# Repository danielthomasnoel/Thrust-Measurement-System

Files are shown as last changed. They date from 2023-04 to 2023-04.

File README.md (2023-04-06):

The Thrust Measurement System (TMS) was conceived to collect reliable propeller performance data in a pedagogical environment. An iterative design review process brought the thrust measurement system from an idea to a product. It applies mechatronic principles to the exploration and quantification of basic fluid dynamics properties, providing a way for the user to accurately measure the thrust generated by a propeller at a variable angular velocity. The TMD is driven by an Arduino microcontroller that collects data from a load cell and an inferred sensor to calculate the thrust and RPM of an attached propellor. LCD screens display both the thrust and RPMs in real time. The propellor’s angular velocity is determined by a potentiometer that limits the power supplied to a DC motor, allowing the user to adjust the rate at which the propellor is turning. This data is recorded and stored on an onboard SD card for further analysis. To maximize the audience and application of the TMD, its construction is designed to be repeatable exportable to other educators.

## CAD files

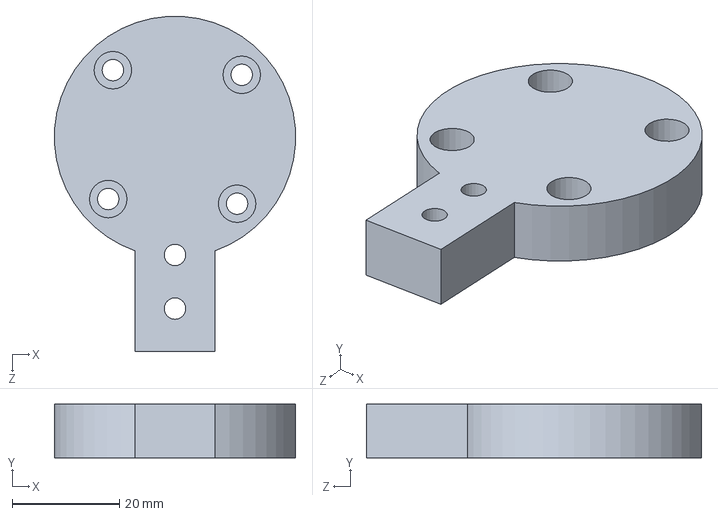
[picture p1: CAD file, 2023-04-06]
DC Motor Mount.SLDPRT
44.9 x 10.0 x 62.5 mm

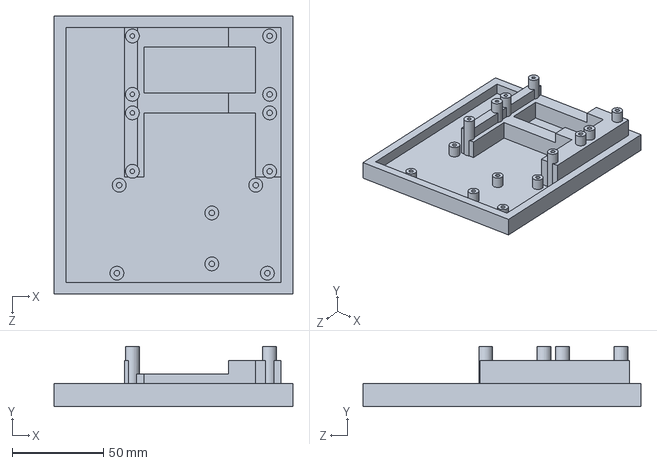
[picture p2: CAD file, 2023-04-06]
Thrust Measurement Control Box.SLDPRT
130.8 x 33.0 x 152.4 mm

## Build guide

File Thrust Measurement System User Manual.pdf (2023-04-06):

Thrust Measurement System User Manual

Daniel Noel¹

, Dr. Michael Davis¹

1University of Southern Maine

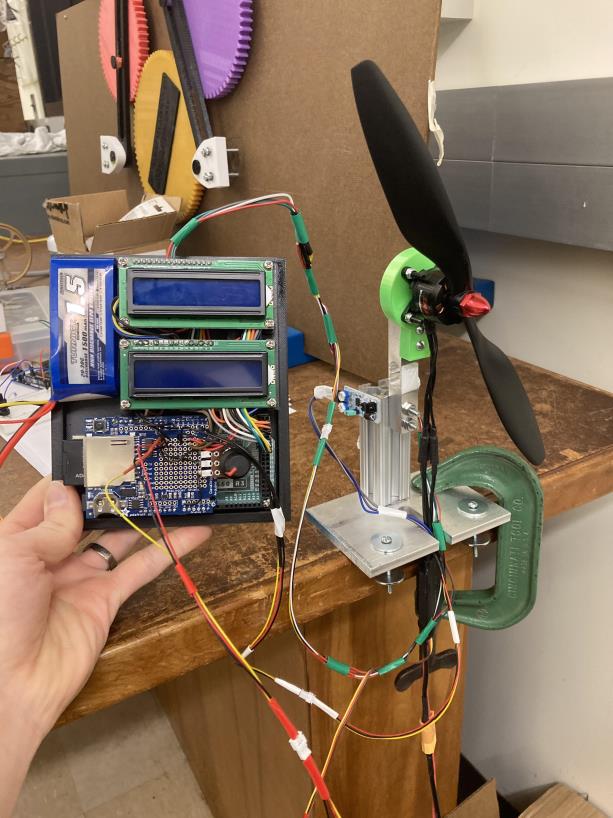
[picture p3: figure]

Author Note

This report was generated as part of the 2022-23 Undergraduate Research Opportunities

Program and was funded by the Maine Space Grant Consortium.

Table of Contents

Purpose

The Thrust Measurement System (TMS) was conceived to collect reliable propeller

performance data in a pedagogical environment. An iterative design review process brought the

thrust measurement device from an idea to a product. It applies mechatronic principles to the

exploration and quantification of basic fluid dynamics properties, providing a way for the user to

accurately measure the thrust generated by a propeller at a variable angular velocity. The TMS is

driven by an Arduino microcontroller that collects data from a load cell and an inferred sensor to

calculate the thrust and RPM of an attached propellor. LCD screens display both the thrust and

RPMs in real time. The propellor’s angular velocity is determined by a potentiometer that limits

the power supplied to a DC motor, allowing the user to adjust the rate at which the propellor is

turning. This data is recorded and stored on an onboard SD card for further analysis. To

maximize the audience and application of the TMS, its construction is designed to be repeatable

exportable to other educators.

Brief Aerodynamics Overview

Thrust is explained by Newton’s third law which states that for every action there is an

equal and opposite reaction. The TMS measures the reaction force generated by the propellor.

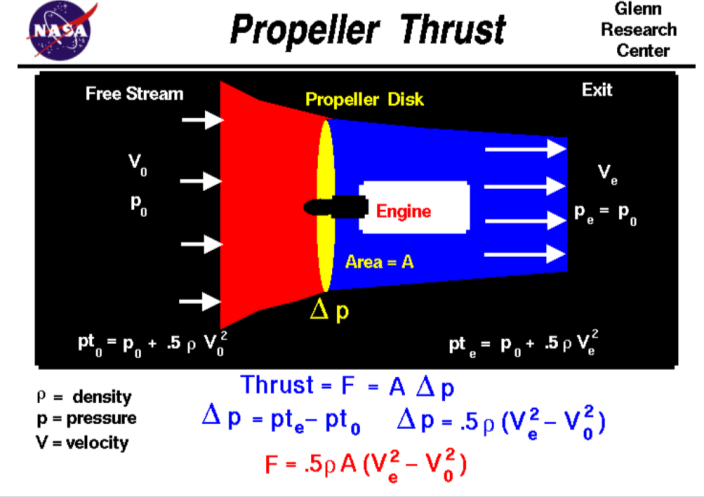
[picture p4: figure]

This is seen in the figure where the thrust

is equal to the product of the propeller’s

area and the pressure difference that it

creates. This pressure differential is the

result of energy conservation and is

proportional to the air’s change in

velocity as it passes through the propeller.

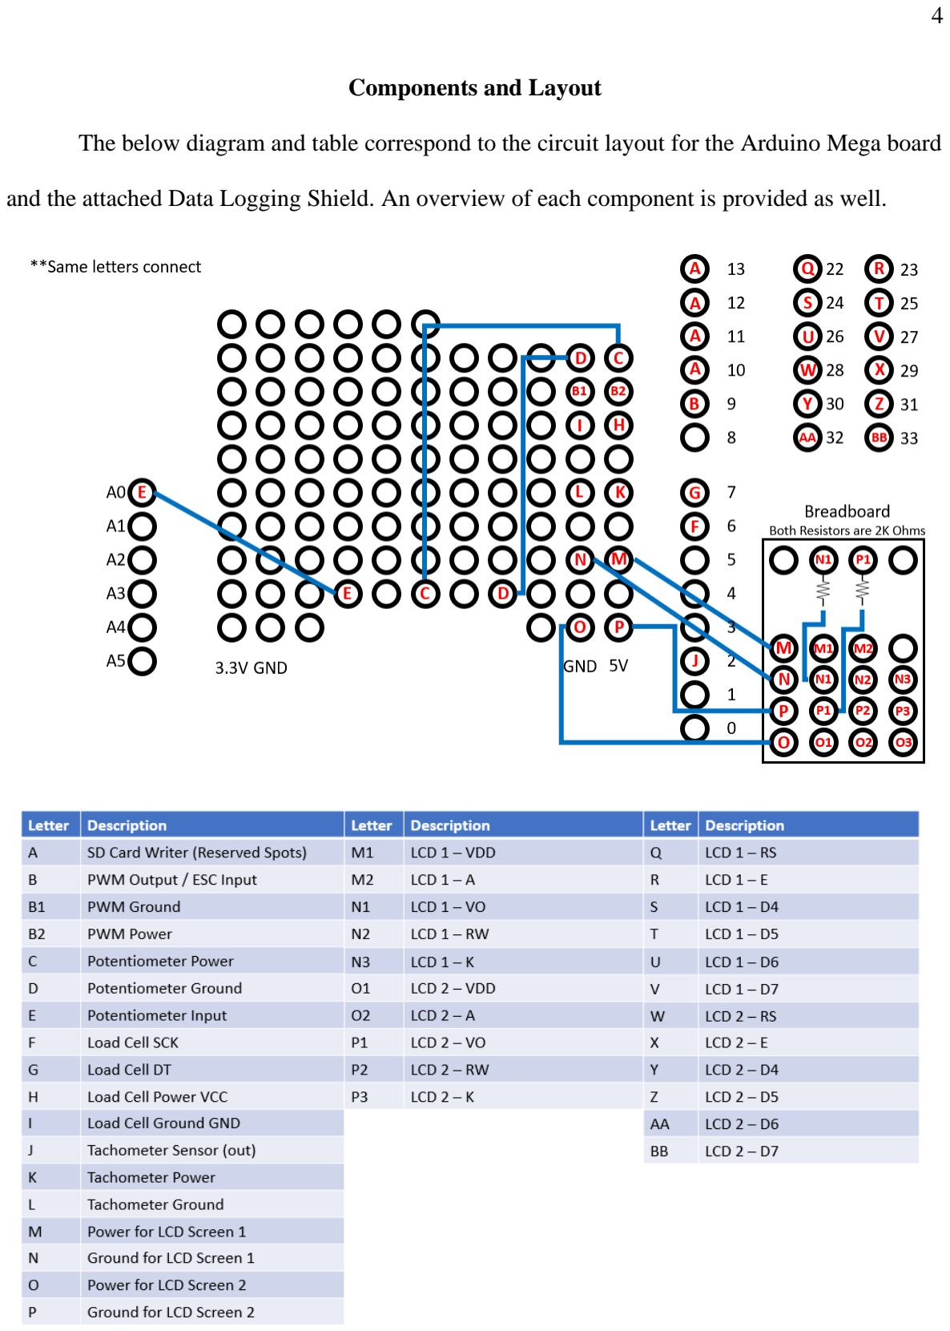
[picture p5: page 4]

Components and Layout

The below diagram and table correspond to the circuit layout for the Arduino Mega board

and the attached Data Logging Shield. An overview of each component is provided as well.

Arduino Mega 2560 R3

The Arduino Mega is a microcontroller board. It has 54 digital

input/output pins, 16 analog inputs, 4 hardware serial ports, a 16

MHz crystal oscillator, a USB connection, a power jack, and a

reset button. All components in the TMS are controlled by and

connected to this device.

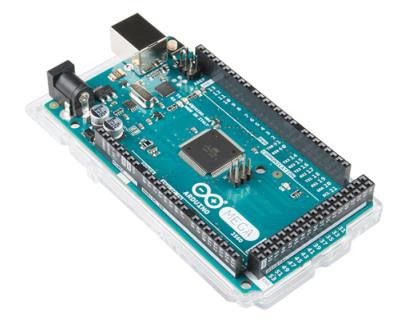
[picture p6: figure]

DC Turbine

The EMAX Multi copter motor MT2213-935KV was used as the DC

turbine. This system allowed for pulse width modulation control which

allows the user to adjust the RPMs of the propellor. This device can rotate

both clockwise and counterclockwise.

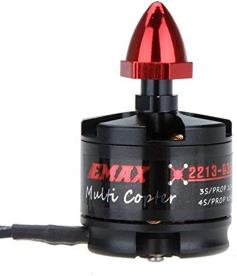
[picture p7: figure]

Potentiometer

The chosen potentiometer was the Panel Mount Right Angle

Potentiometer. It contains a standard linear taper of 10K Ohms,

and it also comes equipped with an on/off switch at the

beginning of the shaft's rotation.

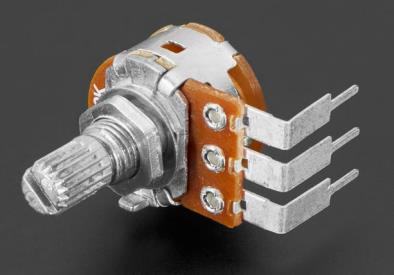
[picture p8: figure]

Load Cell

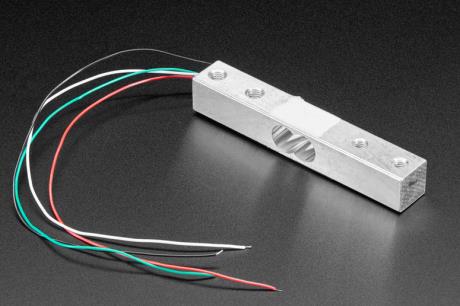
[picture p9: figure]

The load cell chosen was from Adafruit and has a 5kg max

limit. It is a device that converts a force, such as weight,

pressure, or torque, into an electrical signal that can be

measured and standardized.

Tachometer

The Velleman Obstacle Detection IR Sensor was used as a

tachometer by recognizing every time a propellor blade passes

in front of its field of view. It can interface directly with

Arduino, and it also has variable frequency and intensity.

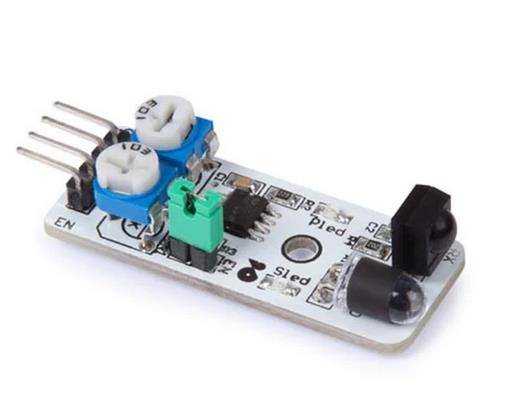
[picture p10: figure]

LCD Screen

The two screens used in the system were HD44780 LCDs.

They display 16 characters wide and 2 rows deep. One was

used to display thrust and the other RPMs.

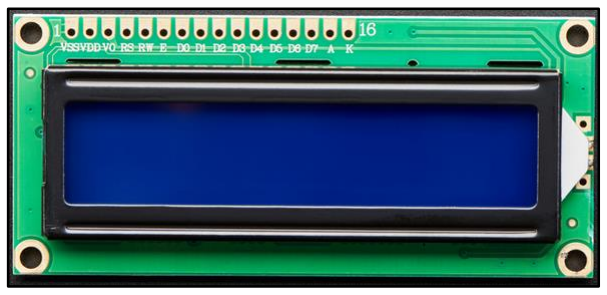
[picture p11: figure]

Data Logging Shield

The data logging shield used was Adafruit Assembled Data

Logging Shield for Arduino. It reads data from the system

outputs and writes them to a removable SD card. This shield

mounts directly on top of the Arduino Mega board.

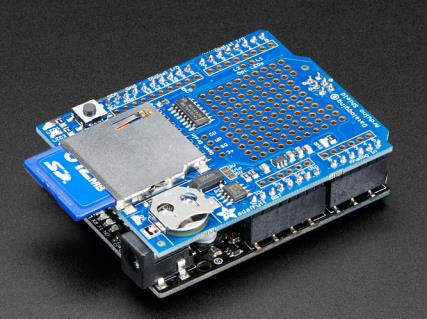
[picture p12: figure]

### 3 Cell 11.1V 1500mAh Battery

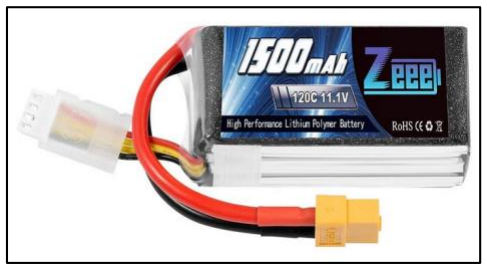
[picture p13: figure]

The type of battery chosen for this project was a 3 Cell

11.1V, 1.5A, 1500mAh battery. A more or less powerful

battery could be substituted if a different range of thrust is

desired.

Arduino Code

The code that needs to be uploaded to the assembled Arduino Mega can be found on

TMS’s GitHub page: https://github.com/danielthomasnoel/Thrust-Measurement-Device. The

code is annotated, but the two main items that may need to be changed for a different setup are

lines 28 and 115. Line 28 is the calibration factor for the load cell which is explained further in

the calibration section. Line 115 needs to be modified depending on how many blades are on the

propellor.

Case Design and Assembly

This system was designed specifically to meet the size requirements of USM’s AeroLab

wind tunnel. The board case will not need to be resized, however for different applications it is

recommended to design all other components to meet specific requirements. The CAD files for

the board case and DC motor mount can be found on the TMS’s GitHub page:

https://github.com/danielthomasnoel/Thrust-Measurement-Device.

The current design requires a soldering station as about 20 connections need to be

soldered directly to the data logging shield. This number can be increased or decreased

depending on the specific specifications of components procured for this build.

Board Case and DC Motor Mount

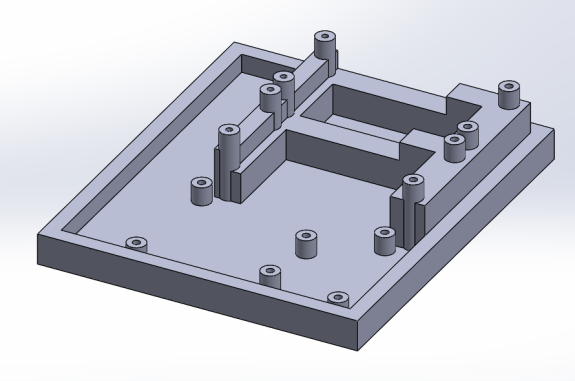
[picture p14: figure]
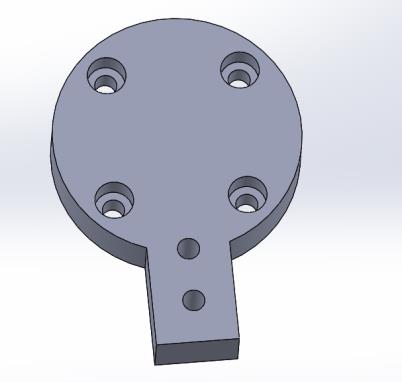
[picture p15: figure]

The board case (left) was designed to fit two LCD screens, 1500 mA battery pack,

Arduino Mega, and data logging shield. All fasteners are sized to have slight interference with

M3 fasteners. The DC motor mount (right) was designed to attach the EMAX DC Turbine to the

load cell. As stated earlier, the specific dimensions of this piece may vary depending on the

system’s size requirements.

Thrust Stand Mount

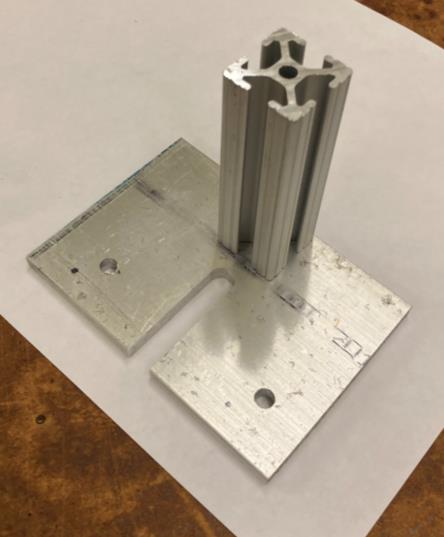
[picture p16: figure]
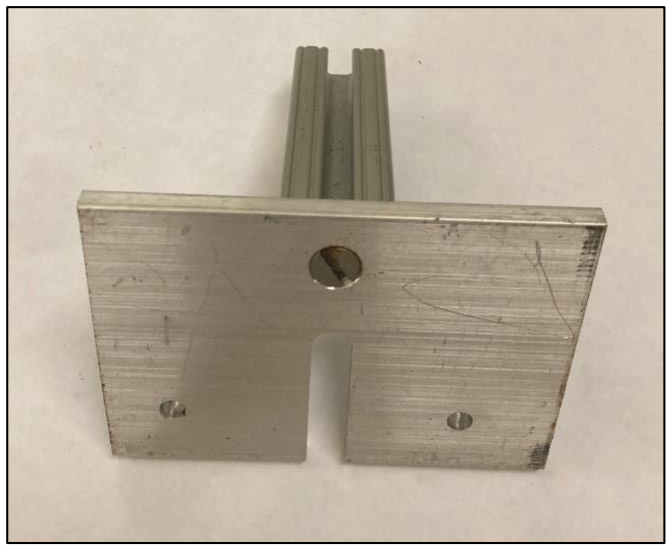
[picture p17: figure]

The aluminum base and 1” 8020 post were sized to fit USM’s AeroLab wind tunnel.

Full Setup

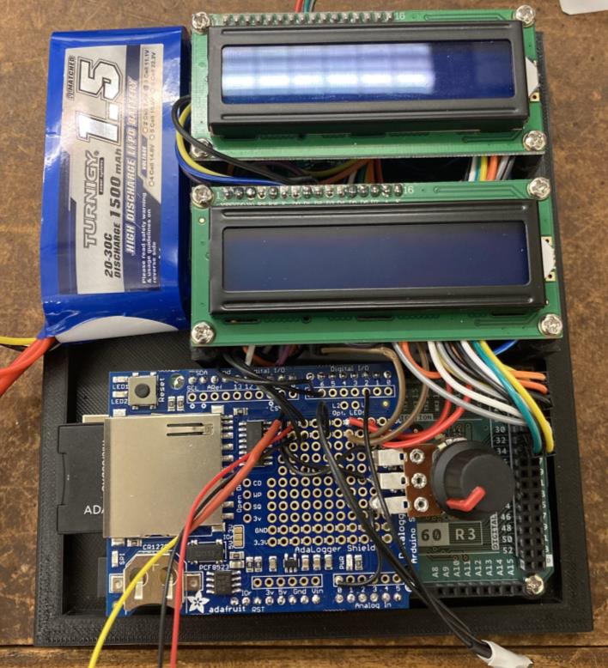
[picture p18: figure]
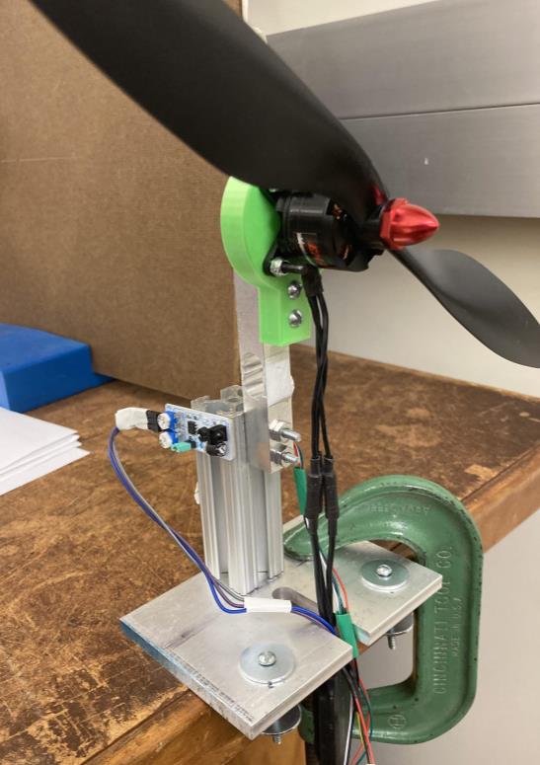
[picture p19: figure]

The fully assembled Thrust Stand Mount (left) is shown with the EMAX DC motor, DC

motor mount, load cell, and tachometer attached. The fully assembled control system is shown

fastened to the Board case. It contains two LCD screens, battery, Arduino Mega, data writing

shield, and potentiometer.

Operation

The first step to operation is to upload the Arduino code from the TMS GitHub to the

fully assembled Arduino Mega and components. It then needs to be calibrated and can be

operated dynamically or by storing data as described below.

Calibration

This system is designed to not needed to be calibrated regularly, generally only after

construction or after making modifications to the system. To calibrate, a known mass is attached

axially in line with the center of the DC motor. This can be done many ways, but for this design it was done by rotating the entire system 90 degrees and attaching the mass with fishing line to

the DC motor. The system is then calibrated iteratively by adjusting line 28 in the Arduino code.

This number needs to be adjusted until the value displayed as thrust on the LCD screen matches

the force applied to the DC motor. Assuming the mass applied is in grams, the mass only needs

to be multiplied by gravity (9.81m/s²
) to convert to millinewtons. This line of code is shown

below, and the calibration factor s currently set to 40, calibrated with a 100g mass or 981mN

force.

These readings should also be checked against manufacturer's data if possible. For this

specific build we were using the EMAX 1045 propellor with 1.5A. To compare the readings to

expected values, the user must interpolate the expected thrust at an known RPM and then

compare the thrust reading to this value. Manufacturer data for this system is shown below.

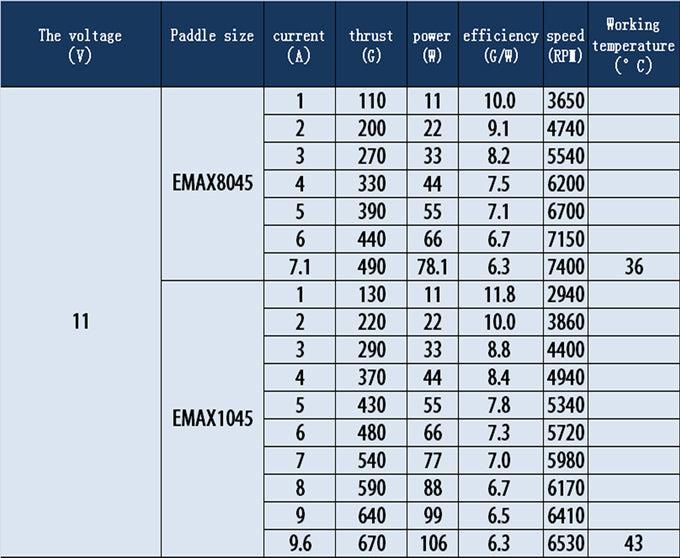
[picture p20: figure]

Dynamic Readings

Once calibrated, the TMS only needs to be reset before every use because this tares the

load cell. It is powered directly by the battery contained in the system. Once the power is on, the

top LCD screen will read either “SD Card Ready” or “SD Card Failure” indicating if the data

storage is operating. After this the knob on the potentiometer is turned to increase the rate the

propellor spins. In this specific system, the propellor needs some manual support to get started,

so the potentiometer should be turned to about 60 degrees clockwise and then the user should

carefully give the propellor a spin. The two LCD screens will now read dynamic thrust in

millinewtons and RPMs. To stop the TMS turn the potentiometer knob counterclockwise until an

audible click is heard.

Data Storage and Retrieval

To retrieve thrust and RPM data over time, the same process as the dynamic readings is

performed with two minor changes. Before starting the test, the SD card needs to be removed

from the system and cleared. Then at the end of the test, you simply remove the SD card, and it

will contain about 1 data point for every .75 seconds elapsed.

Bill of Materials

The approximate bill of materials is shown in the table below with a total of $165.23. Of

note, some materials used for this build were available for free use at our facility so were not

included in this list. These include Thrust Stand aluminum pieces (plate and 8020), 3D printer

and filament, extension wires, soldering equipment and materials, and most hardware.

Contact Information

Daniel Noel | Dr. Michael Davis
daniel.t.noel@maine.edu | michael.p.davis@maine.edu
danielthomasnoel@gmail.com
Item Number | Supplier Name | Catalog Number Product Description | | Quantity | Unit of Measure Price
1 | AdaFruit | 4722 | 1.25mm Pitch 4-pin Cable Matching Pair - 40cm long - Molex PicoBlade Compatible | 2 | Pair of Wires $1.90
2 | AdaFruit | 4721 | 1.25mm Pitch 3-pin Cable Matching Pair - 40cm long - Molex PicoBlade Compatible | 3 | Pack | $2.85
3 | AdaFruit | 4685 | Black Nylon Machine Screw and Stand-off Set – M3 Thread | 1 | Box | $16.95
4 | AdaFruit | 344 | Heat Shrink Pack | 1 | Pack | $4.95
5 | AdaFruit | 181 | Standard LCD 16x2 + extras - white on blue | 2 | Board | $19.90
6 | AdaFruit | 2046 | Potentiometer Knob - Soft Touch T18 - Red | 1 | Knob | $0.50
7 | AdaFruit | 3395 | Panel Mount Right Angle 10K Linear Potentiometer w/On-Off Switch - 10K Linear w/ Switch | 1 | Knob | $1.50
8 | SparkFun | DEV-11061 | Arduino Mega 2560 R3 | 1 | Board | $48.95
9 | Robotshop | RB-Vel-231 | Obstacle Detection IR Sensor | 2 | # of Boards $10.48
10 | Adafruit | 4541 | Strain Gauge Load Cell (5 kg) | 2 | # of Gauges | $7.90
11 | Adafruit | 1294 | SD/MicroSD Memory Card (8 GB SDHC) | 2 | # of SD Cards $19.90
12 | Adafruit | 1141 | Adafruit Assembled Data Logging shield for Arduino | 1 | # of Boards $13.95
13 | EMAX | 101005002 | EMAX Multicopter motor MT2213 (With Prop1045 Combo) 935KV | 1 | Set | $15.50

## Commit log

2023-04-06 Create Arduino Code
2023-04-06 Update Arduino Code
